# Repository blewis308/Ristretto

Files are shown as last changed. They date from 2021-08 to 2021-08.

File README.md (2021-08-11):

# Ristretto hub!

Here is a comprehensive hub for the Ristretto Keyboard, written by **Fruit**
<br/>

## Repository Contents:
* firmware
    * everything firmware related including keymaps, hex's, and more!
    * Check out the [QMK Repo](https://github.com/qmk/qmk_firmware/tree/master/keyboards/ristretto) for big firmware releases.
* open source
    * all the pieces of this board that will be free for use (i.e. plate files, midplate stl, etc.)
    * *Please note:* if the file does not exist in here, it is not open source and unauthorized copying of the files via any medium is strictly prohibited.
    * midLayer.stl scale is fucked, scale it so z-axis is 10mm tall - you can also purchase one from [Noah K on his store](https://kiserdesigns.bigcartel.com/product/ristretto-midlayer)
* img
    * image files for this page.

## Table of Contents

* [prerequisites](#prerequisetes)
* [components](#components)
* [assembly](#assembly)

<br/>

## prerequisites

There are some items you will need in order to build your Ristretto

### Required

* A soldering iron
* Solder
* A small phillips screwdriver

### Optional

* Flux - if you are not using leaded solder, flux is recommended
* a little bit of tape
* a sick [P3D Acrylic case](https://p3dstore.com/collections/40-or-smaller-acrylic-cases/products/ristretto-acrylic-gasket-mount-keyboard-case) from the [P3D Store](https://p3dstore.com/collections/40-or-smaller-acrylic-cases/products/ristretto-acrylic-gasket-mount-keyboard-case)! 

<br/>

## components

Included in each kit is the following:
#### Bottom Plate
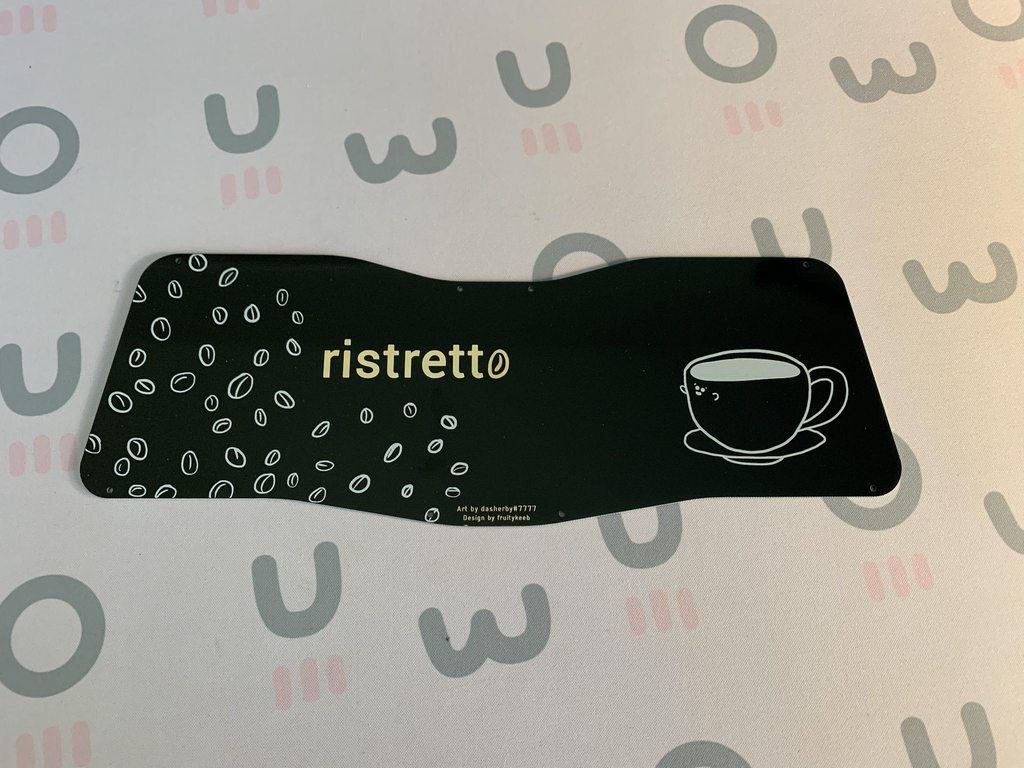
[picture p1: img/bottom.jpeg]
Bottom Plate

#### Switch Plate
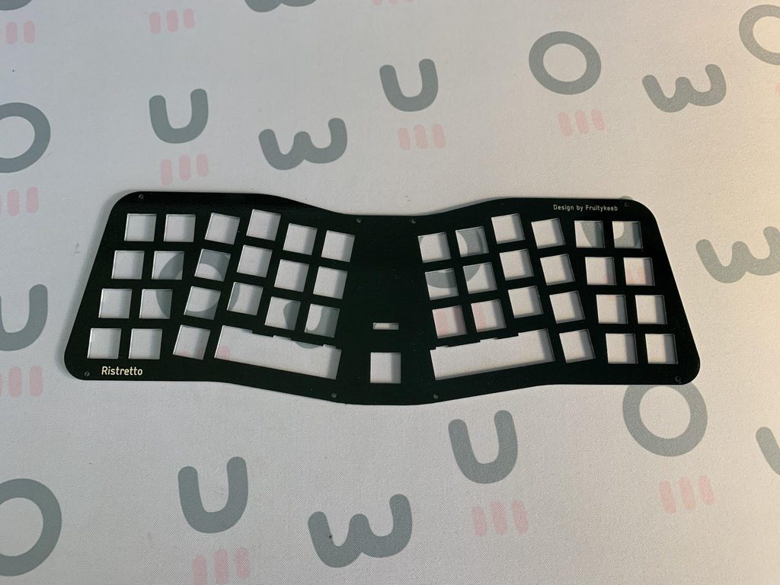
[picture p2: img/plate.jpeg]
Switch Plate

#### Assembled PCB
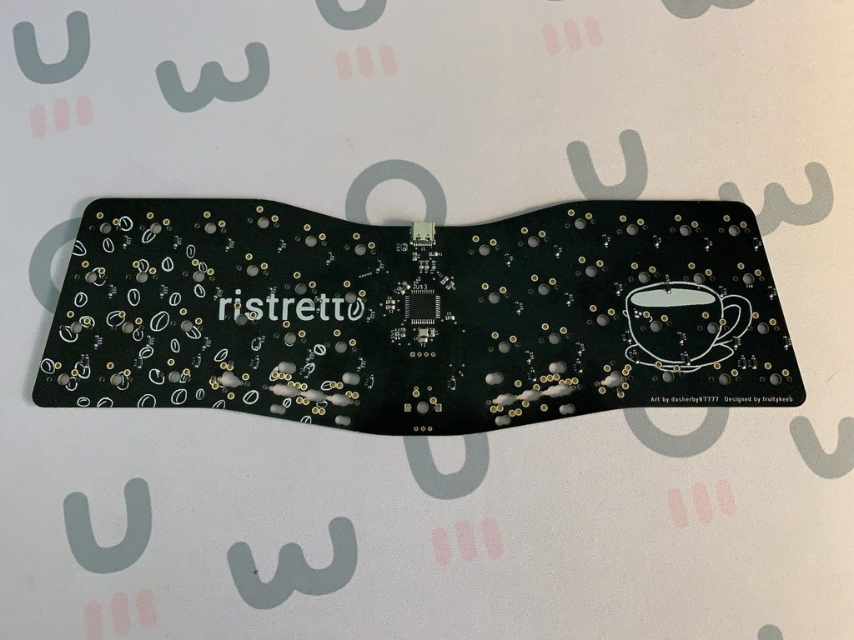
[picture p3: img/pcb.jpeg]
PCB

#### OLED Module
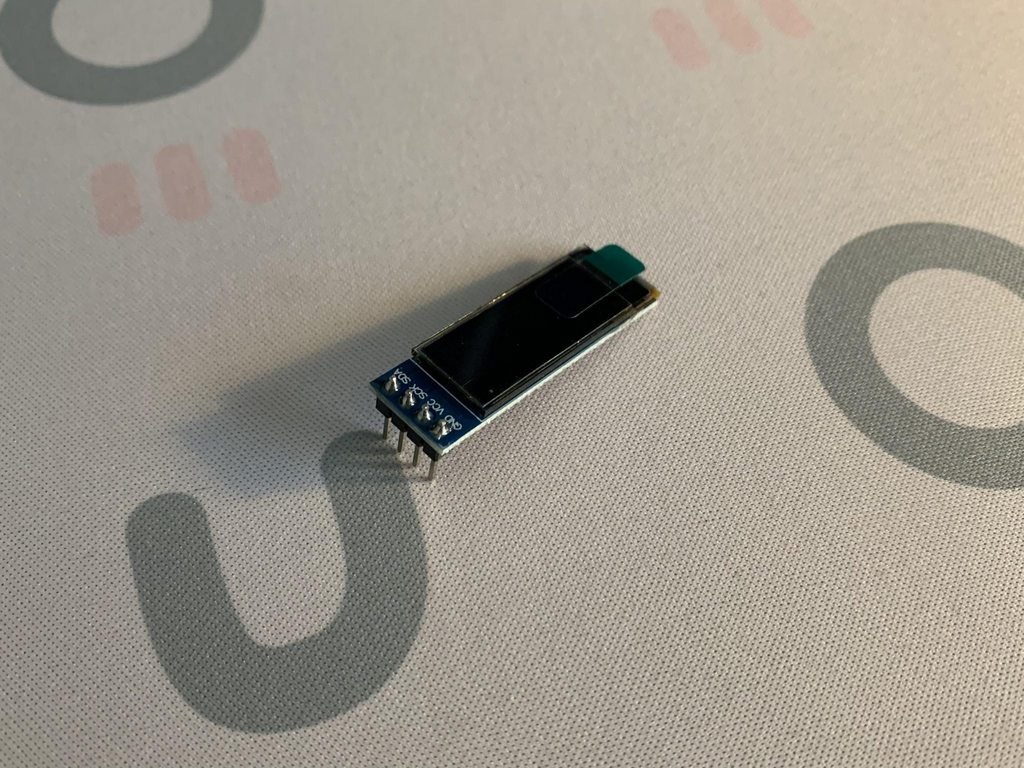
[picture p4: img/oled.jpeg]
OLED Module

* 0.91" I2C OLED
#### Encoder and Knob
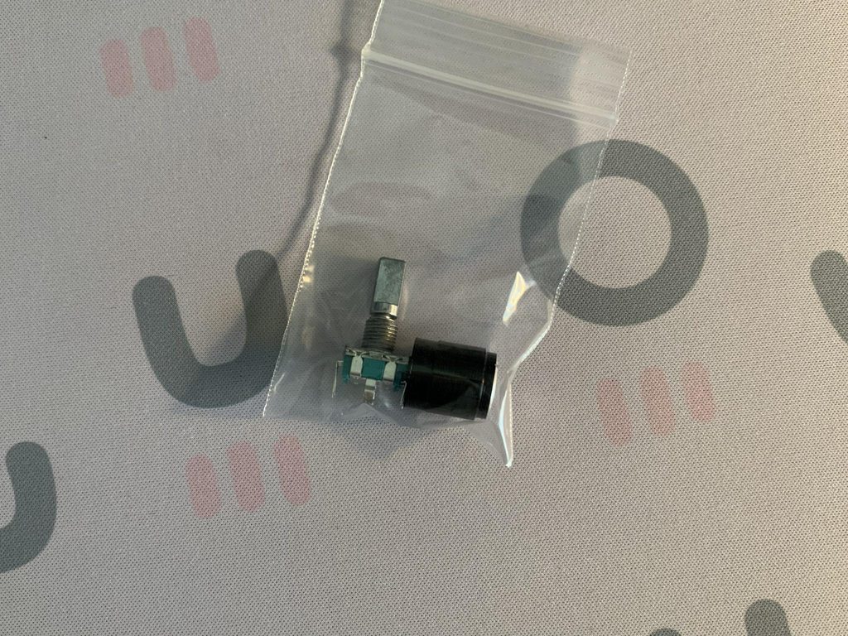
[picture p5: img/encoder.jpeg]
Encoder and Knob

* EC11 Encoder
#### Screws and Standoffs
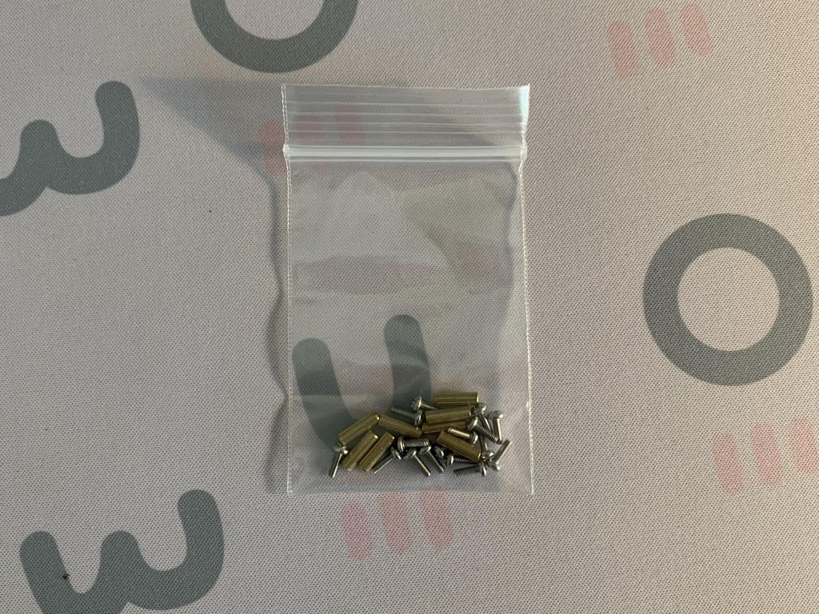
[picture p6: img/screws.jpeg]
Screws and Standoffs

* Screws are M2 x 6mm - 16 qty
* Standoffs are M2 x 10mm - 8 qty
#### Rubber Feet
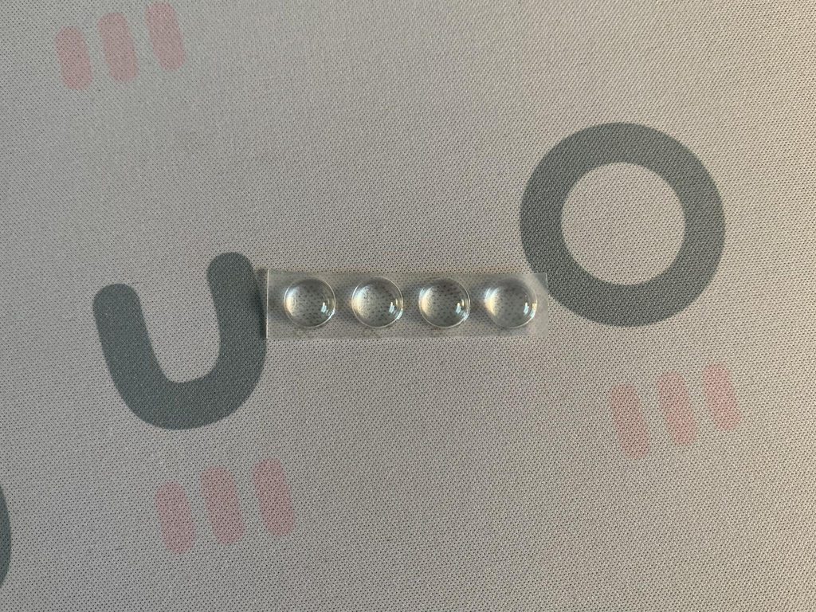
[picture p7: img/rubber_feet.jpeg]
Rubber Feetsies


## assembly
### Total Estimated Time: 1 hour

#### Before you begin!
Please test your PCB. These were all tested before shipping, but double check that all the switches work by shorting them with a pair of conductive tweezers. As soon as a soldering iron touches the board, I am no longer able to issue a refund/replacement. Please refer to the [terms and conditions](https://www.fruitykeeb.xyz/terms-and-conditions) listed on my site for more info.

Note about this guide: For this guide, I am building a board with the OLED and no encoder - instead of the encoder there is a switch in its place. I will still point out where the encoder goes.

PS. If you are using the [P3D Acrylic case](https://p3dstore.com/collections/40-or-smaller-acrylic-cases/products/ristretto-acrylic-gasket-mount-keyboard-case) (highly recommended!! it's super cool!!), make sure you follow [Jake's instructions](https://p3dstore.com/pages/revised-acrylic-gasket-case-build-guide) to put together your case!

### Step 0: Solder the Encoder (optional)
Step 0 thx dood
The encoder goes at the bottom middle of the PCB. **Make sure the legs stick through to the side with the all the components on it.**

#### If you are millmaxing the board, do that now - **as well as stabilizers**. Check the KLE [here](http://www.keyboard-layout-editor.com/#/gists/95d1aea85be3f3f5c29b4fbeddd9893c).

### Step 1: Put some switches into the plate
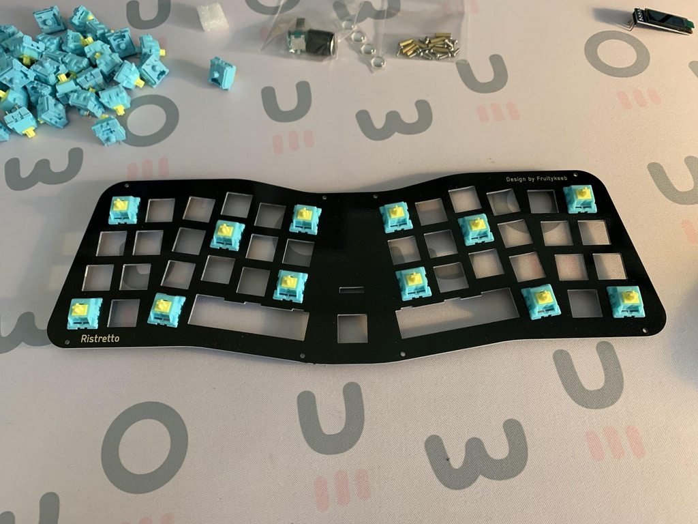
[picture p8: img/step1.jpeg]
Step 1

I usually put 5 or 6 on each side in the locations shown, this just helps keep the plate up when you are putting in the rest. 

### Step 2: Flip the plate over and put the PCB on
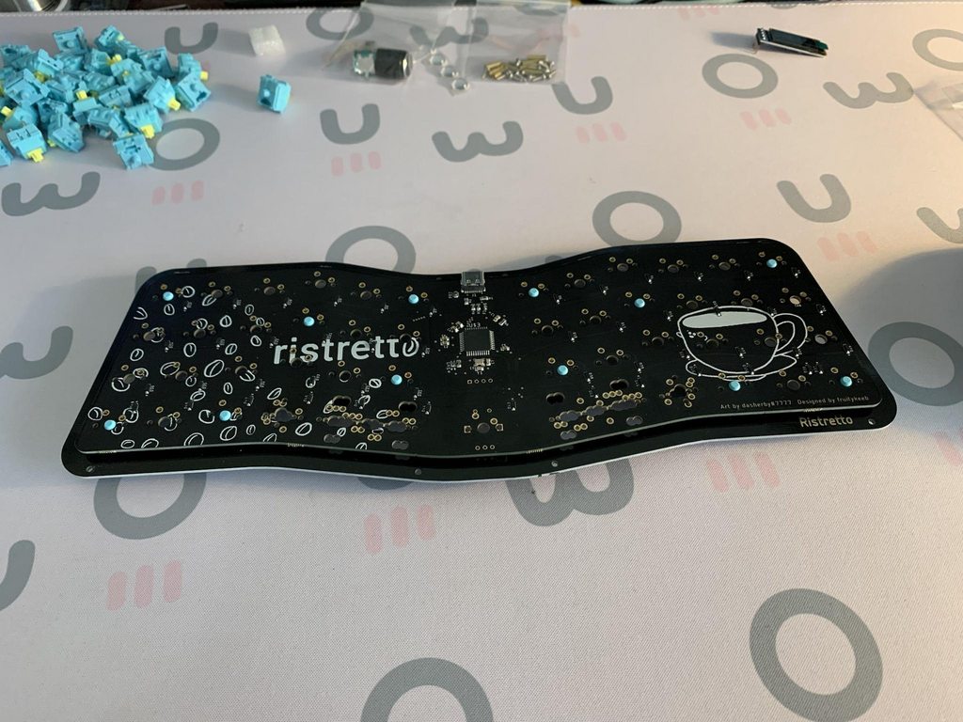
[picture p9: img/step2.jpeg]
Step 2

Please be gentle as 5 pin switches will need some force because the tolerances are tight.

### Step 3: Solder those switches in place
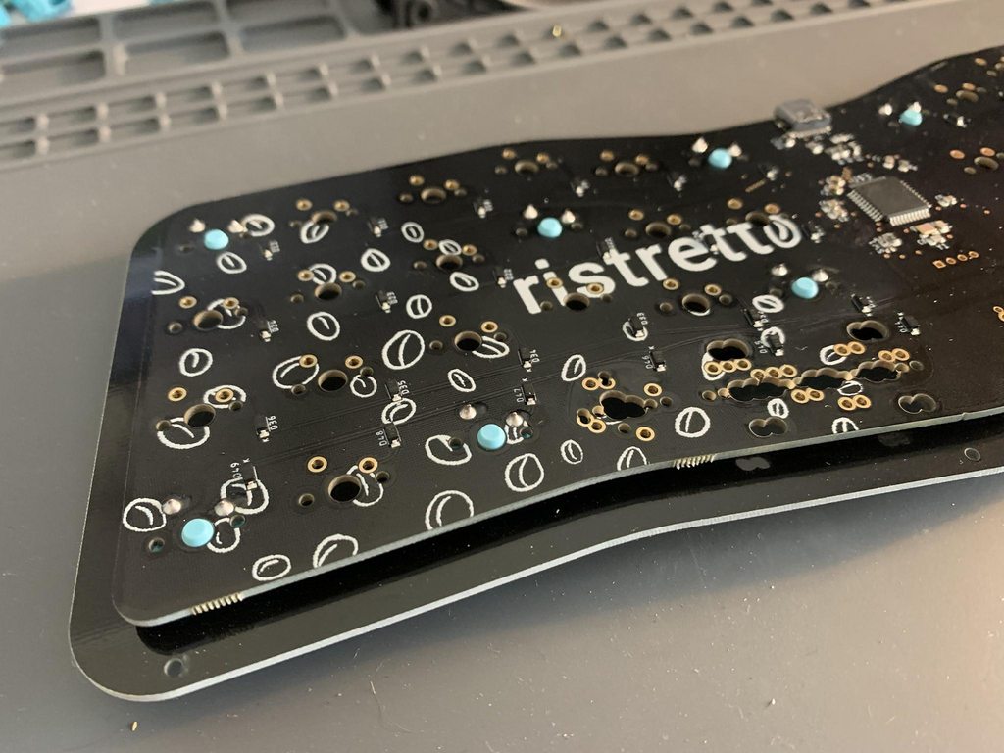
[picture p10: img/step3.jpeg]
Step 3


### Step 4: Flip the board back over and insert the remaining switches
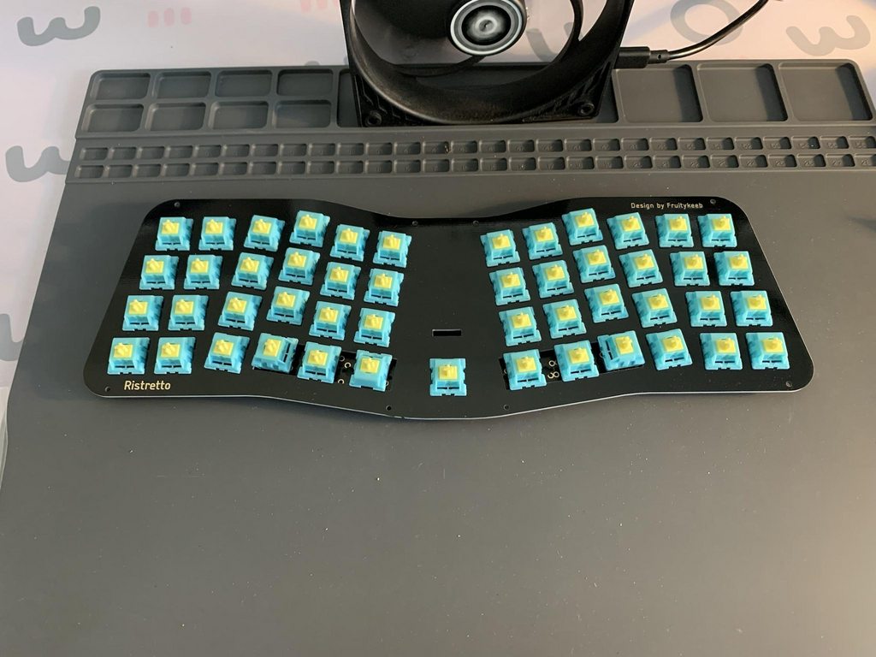
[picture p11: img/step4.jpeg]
Step 4

Here is where you do the thumb layouts... I may have been dumb and not put any notes *on* the pcb, but I'll drop that here. (I know, I am bad a ms paint)
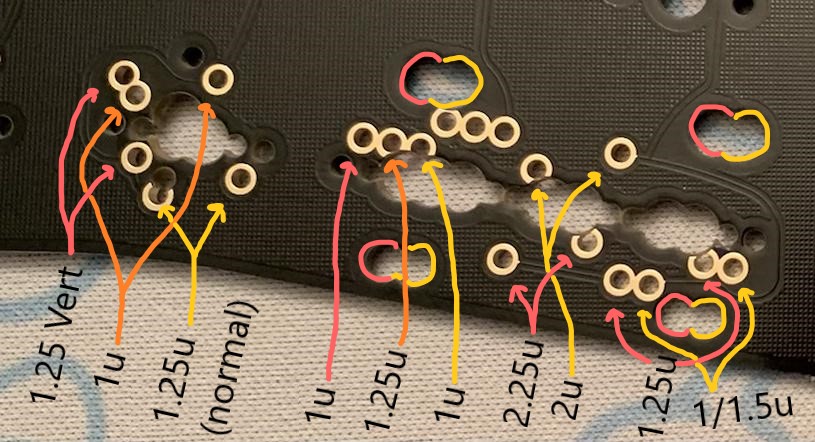
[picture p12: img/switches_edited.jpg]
PCB Notes


### Step 5: Flip the board over again (flip flop flip flop) and solder all the switches
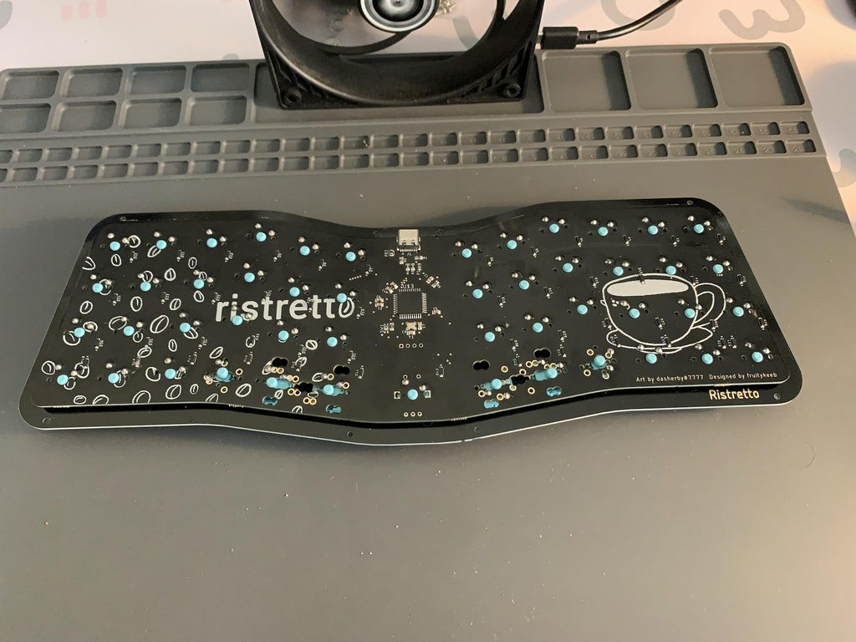
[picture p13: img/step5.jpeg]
Step 5


### Step 6: Flip the board back over again and insert the OLED module (optional)
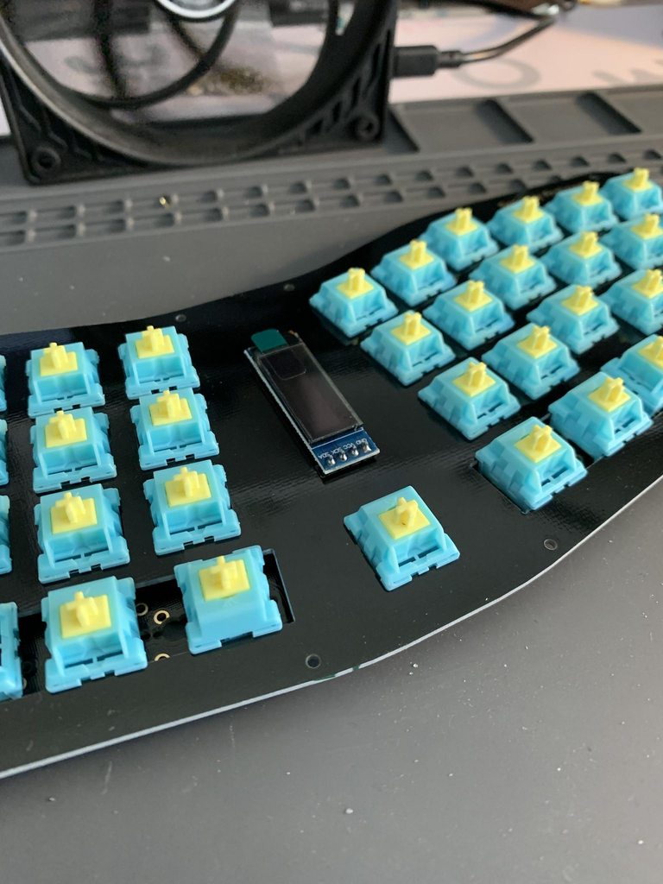
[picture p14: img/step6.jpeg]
Step 6


Use some tape to hold this in until it is soldered.

### Step 7: Flip the board over yet again, solder in the OLED module, and add the screws and standoffs to the plate
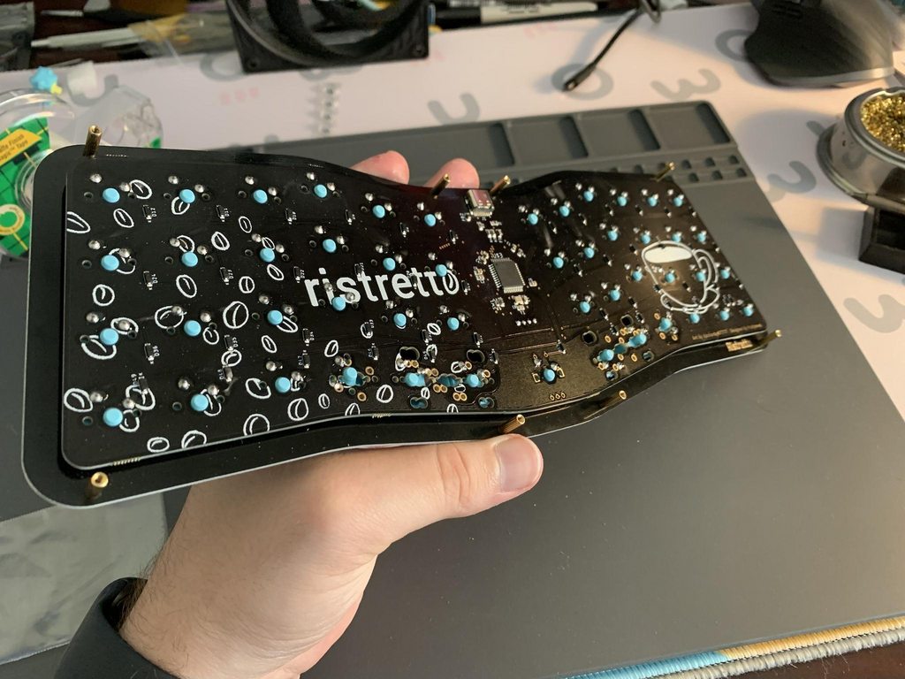
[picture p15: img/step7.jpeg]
Step 7

This is kinda tricky as the tolerances are tight, but the legs should *just* poke through the PCB.

### Step 8: Add the bottom plate on and screw it in, add the rubber feet
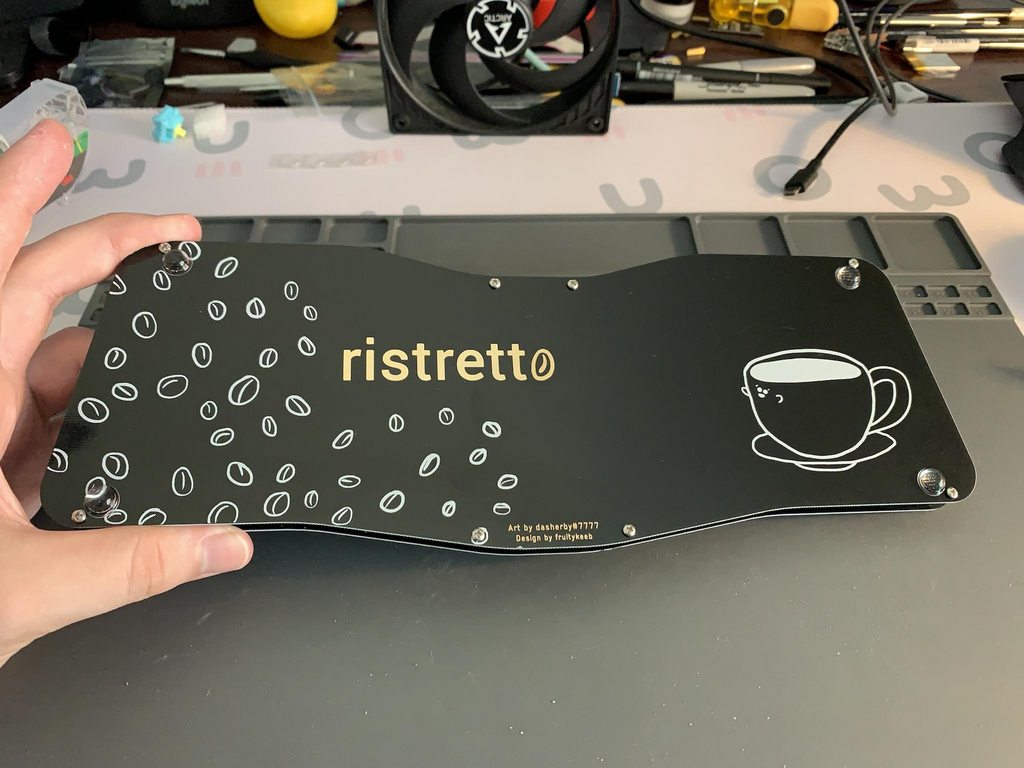
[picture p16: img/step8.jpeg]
Step 8

I recommend putting the rubber feetsies right on the inside of the screws, but you can put them just about anywhere you want. 

What? It's not like I know where you live and will show up at your house one night and force you to put them in a decent location. But hey, you do you. :clap:

### Step 9: Add keycaps and drooool :cold_sweat:
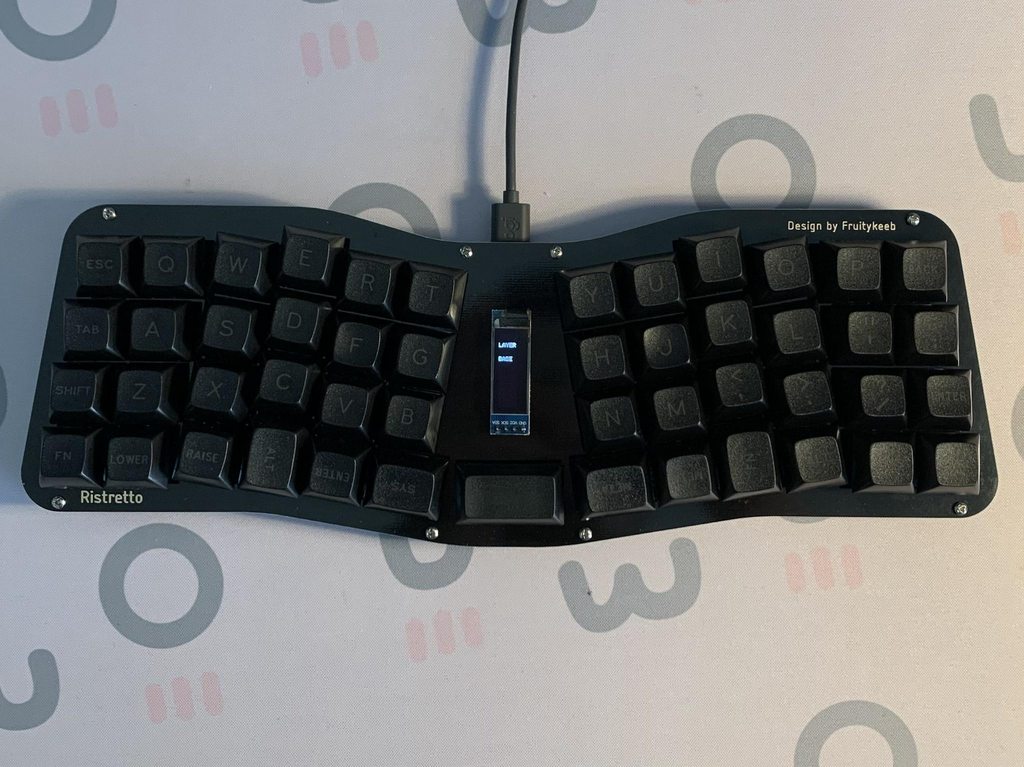
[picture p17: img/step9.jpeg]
Step 9

Oh yeah, that's a hot board. Nice job :ok_hand:

Post some pics in the [Fruitkeeb Discord](https://discord.gg/Qzrua9V2Ec) and show off your hard work!!

> Keycaps used in pic is DSS Lights Out from RingerKeys

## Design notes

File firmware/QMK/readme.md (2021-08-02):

# Ristretto

Ristretto
Ristretto-2

An Integrated, Column Stagger, 40% Keyboard with OLED and Rotary Encoder

* Keyboard Maintainer: [Fruit](https://github.com/Blewis308)
* Hardware Supported: Ristretto PCB, Atmega32u4
* Hardware Availability: Through Group Buy - May 2021

    To enter the bootloader, press the button marked "SW1" on the bottom of the PCB.

Make example for this keyboard (after setting up your build envionment):

    make ristretto:default

See the [build environment setup](https://docs.qmk.fm/#/getting_started_build_tools) and the [make instructions](https://docs.qmk.fm/#/getting_started_make_guide) for more information. Brand new to QMK? Start with our [Complete Newbs Guide](https://docs.qmk.fm/#/newbs).

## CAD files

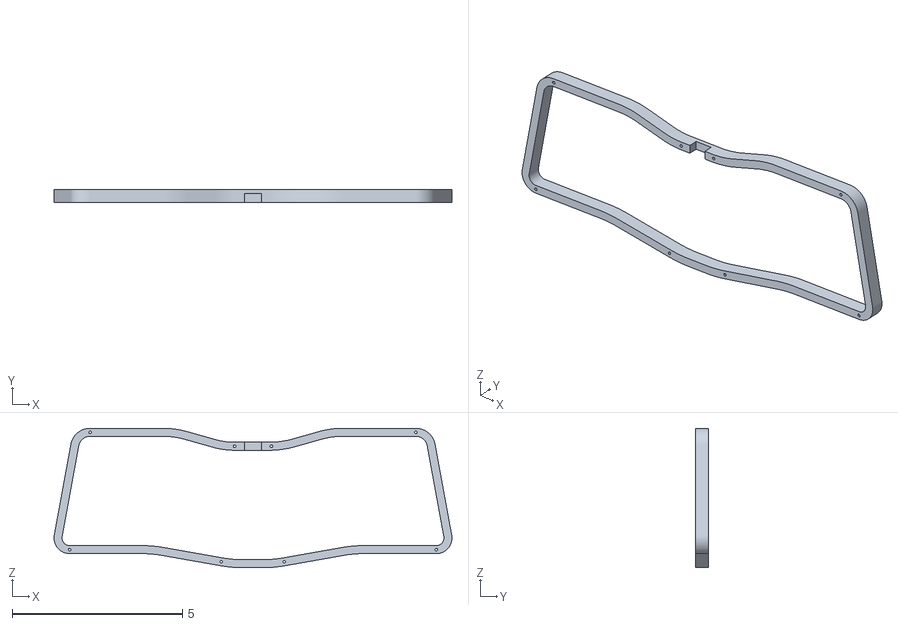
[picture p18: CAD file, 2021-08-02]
open source/midLayer.stl
11.7 x 0.394 x 4.09

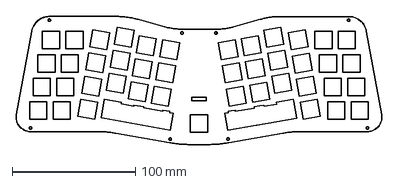
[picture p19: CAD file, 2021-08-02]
open source/switchplate.dxf
296.7 x 103.9 mm

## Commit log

2021-08-02 Add files n stuff
    [midLayer.stl, switchplate.dxf]
2021-08-02 shill p3d
    https://p3dstore.com/collections/40-or-smaller-acrylic-cases/products/ristretto-acrylic-gasket-mount-keyboard-case
